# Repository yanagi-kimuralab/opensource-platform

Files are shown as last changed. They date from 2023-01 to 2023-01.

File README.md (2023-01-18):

# opensource-platform


# オープンソースプラットフォームとは
opensource-platformは、長岡技術科学大学木村研究室が開発・提供しているレスキュー対応ロボットのためのプラットフォームです。<br>
本プラットフォームはすべてのハードウェアがオープンソースハードウェアとして公開されています。

# 3Dモデルビューア
Autodesk Viewerを使用して、ブラウザ上で3Dモデルを閲覧・操作することができます。<br>
アクセスは[こちら](https://autode.sk/3wbROCn)から。

# 基本コンセプト
開発したプラットフォームは以下のコンセプトで開発されています。

・大学、高専生が製作可能であること<br>
・大学、高専等の設備で製造可能であること<br>
・様々な要求仕様に対応できること<br>
・災害対応ロボット競技会などの実証実験に使用できること<br>

# 基本仕様
オープンソースロボットプラットフォームの基本性能及びCADの書き方について以下に示します。



加工での注意点などは[wiki](https://github.com/yanagi-kimuralab/opensource-platform/wiki)に記載

# 使用ソフト環境
SOLIDWORKS 2018<br>
Vectric Cut2D<br>
Estlcam<br>

その他使用ソフトはこちら

ご不明なことがあればこちらに連絡ください。<br>
メール：stn.kimuralab@gmail.com

# ライセンス
opensource-platform is licensed under the Creative Commons Attribution-ShareAlike 4.0 International License.<br>
<br>

CADのライセンス問題があるため、SOLIDWORKSデータの提供については別途お問い合わせ願います。<br>

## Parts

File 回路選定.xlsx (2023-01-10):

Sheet: アークテクチャ記述
 | 使用アクチュエータ種類 | モータ 型番 |  |  | コネクタ |  | ケーブル |  | コネクタ | モータドライバ | コネクタ | ケーブル | コネクタ |  | サブCPU | ケーブル | メインPC
メインクローラL | モータ |  | 信号線 |  |  |  | 28AWG,10芯 |  | DIN 41651 | EPOS4 Compact 50/15 CAN | Molex CLIK-Mate, 1 列 , 4 極 (502578-0400) | ２８AWG ４芯 |  | CAN－BUSシールド | Arduino uno |  | NUC
 |  |  | 電源線 | モータ |  |  | 16AWG |  | Molex Mega-Fit, 4 極 (171692-0104) |  | Molex Mega-Fit, 2 極 (171692-0102) | 14AWG |  |  | ターミナル10P＊２ |  | ２４V バッテリー
メインクローラR | モータ |  |  |  | EHR-4 |  |  |  |  | EPOS4 Compact 50/15 CAN |  |  |  | CANシールド | Arduino uno
フリッパーFL | モータ | H54-200-S500-R | 信号線 |  |  |  | 28AWG,8芯 |  | molex SPOX™ | u2d2 | EHR-4 | ２８AWG ４芯 |  |  | デイジーチェーン
 |  |  | 電源線 |  |  |  | 16AWG |  | 39-01-2020
フリッパーFR | モータ | H54-200-S500-R |  |  |  |  |  |  |  | デイジーチェーン |  |  |  |  | デイジーチェーン
フリッパーRL | モータ | H54-200-S500-R |  |  |  |  |  |  |  | デイジーチェーン |  |  |  |  | デイジーチェーン
フリッパーRR | モータ | H54-200-S500-R |  |  |  |  |  |  |  | デイジーチェーン |  |  |  |  | デイジーチェーン
EPOS4 Compact 50/15 CAN |  | 最大出力電流Imax 30 A |  |  |  | 連続出力電流 Icount 15 A |  | 電源電圧Vcc (最大値) 50 V
https://www.maxongroup.co.jp/maxon/view/product/control/Positionierung/520886
 |  |  |  |  |  |  | 連続出力9.3A
ダイナミクセルモータ PH54-200-S500-R（H54-200-S500-R互換品
https://e-shop.robotis.co.jp/product.php?id=285

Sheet: 物品リスト
 | 箇所 | 区分 | 種類 | メーカ型番等 | サイト商品名 | 品番 | 注文コード | 必要個数 | 単価（税別） | 合計(税別 ) | 販売店 | リンク
 | メインクローラ | モータ |  |  | 組み合わせ ギアヘッド：プラネタリギアヘッド GP 42 C Ø42 mm, 3 - 15 Nm, セラミック･バージョン モータ：G32RE 40 Ø40 mm, グラファイトブラシ, 150 Watt センサ:エンコーダ MR, Type L, 500 カウント/回転, 3 チャンネル, ラインドライバ | 309293 |  | 2 | 117000 | 234000 | maxon | https://www.maxongroup.co.jp/maxon/view/content/cart
 | メインクローラ | MD |  | EPOS4 Compact 50/15 CAN | EPOS4 Compact 50/15 CAN, デジタル位置制御ユニット, 15 A, 10 - 50 VDC | 520886 |  | 4 | 80000 | 320000 | maxon | https://www.maxongroup.co.jp/maxon/view/product/control/Positionierung/520886
 | メインクローラ | 電源線 MD input（X1 | コネクタ ハウジング | Molex Mega-Fit, 2 極 (171692-0102) | Mega-Fit シリーズ 171692-0102、1個 | 171692-0102 | 29075105 | 40 | 58 | 2320 | モノタロウ | https://www.monotaro.com/p/2907/5105/ | 電線サイズ（AWG）:12～16
 | メインクローラ | 電源線 MD Output（X3b | コネクタ ハウジング | Molex Mega-Fit, 4 極 (171692-0104) | Mega-Fit シリーズ | 171692-0104 | 29075114 | 40 | 63 | 2520 | モノタロウ | https://www.monotaro.com/p/2907/5114/
 | メインクローラ | 電源線 MD | コネクタ コンタクト | Molex Mega-Fit, メスクリンプ端子 (172063) | Molex 端子 Mega-Fitシリーズ メス 圧着 | 172063-0311 | 58276576 | 2 | 7790 | 15580 | モノタロウ | https://www.monotaro.com/p/5827/6576/
 | メインクローラ | 電源線 MD→モータ | ケーブル | 14awg | FA用300V電源・低速移動屈曲配線ケーブルシールド有 | ロボトップ(DPC3-SB/2517)AWG14(2.0sq)2c | 34967055 | 5 | 1390 | 6950 | モノタロウ | https://www.monotaro.com/p/3496/7055/
 | メインクローラ | 電源線 ターミナル→MD | ケーブル | 1６awg | 16 awgシリコンワイヤ、20m / 66フィート柔軟で錫メッキされた銅線高耐熱10m黒と10m赤線は3Dプリンタ用、テストリード用、RCアプリ用 |  | B07H4HW3QY | 1 | ¥1999 | 1999 | アマゾン | https://www.amazon.co.jp/TUOFENG-16-awg%E3%82%B7%E3%83%AA%E3%82%B3%E3%83%B3%E3%83%AF%E3%82%A4%E3%83%A4%E3%80%8120m-66%E3%83%95%E3%82%A3%E3%83%BC%E3%83%88%E6%9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
 | メインクローラ | 信号線 MD CAN(X11 | コネクタ ハウジング | Molex CLIK-Mate, 1 列 , 4 極 (502578-0400) | Molex コネクタハウジング 4極 ピッチ：2mm 1列 502578-0400 | 896-7608 |  | 20 | ¥30.9 | 618 | RS | https://jp.rs-online.com/web/p/wire-housings-plugs/8967608/
 | メインクローラ | 信号線 MD CAN(X11 | コネクタ コンタクト | Molex CLIK-Mate クリンプ端子 (502579) | Molex 端子 CLIK-Mateシリーズ オス 圧着 | 720-6078 |  | 100 | ¥3.61 | 361 | RS | https://jp.rs-online.com/web/p/crimp-contacts/7206078/
 | メインクローラ | 信号線 MD エンコーダ(X5 | コネクタA | DIN 41651 メスコネクタ , ピッチ 2.54 mm, 10 極 , ストレイン･リリーフ付き) | リボンケーブルコネクタ RS Pro， メス， 10極， 2列 | 625-7369 | 41272273 | 20 | 379 | 7580 | モノタロウ | https://www.monotaro.com/p/4127/2273/
 | メインクローラ | 信号線 MD エンコーダ(X5 | コネクタB | DIN 41651 オスコネクタ , ピッチ 2.54 mm, 10 極 , ストレイン･リリーフ付き | RS PRO IDCコネクタ 10極, 2列 オス 2.54mmピッチ | 625-7252 |  | 4 | 344 | 1376 | RS | https://jp.rs-online.com/web/p/idc-connectors/6257252
 | メインクローラ | 信号線 MD エンコーダ(X5 | 圧接工具 |  | RS Pro 圧着工具 | 235-6428 | 41223763 | 1 | 3890 | 3890 | モノタロウ | https://www.monotaro.com/p/4122/3763/
 | メインクローラ | 信号線 10芯 シールド線 |  | 28AWG、10芯 | スリムロボットケーブル | KRT AWG28 X 10C 5m | 05233908 | 2 | 2990 | 5980 | モノタロウ | https://www.monotaro.com/p/0523/3908/
 | メインクローラ | 信号線 ４芯ケーブル |  | 26AWGぐらい12芯 | RKVリボンコード | RKV0.12mm/10CX12C 3m | 05234136 | 3 | 749 | 2247 | モノタロウ | https://www.monotaro.com/p/0523/4136/?t.q=%83%8A%83%7B%83%93%83P%81%5B%83u%83%8B%81%404%90c
税込み | メインクローラ | 信号線 | Arduino拡張 | SeeedStudio CAN-BUSシールド V2 | SeeedStudio CAN-BUSシールド V2 |  | SEEED-103030215 | 2 | 3421 | 6842 | SWITCHSCIENCE | https://www.switch-science.com/catalog/3435/
税込み | メインクローラ | 信号線 | Arduino |  | Arduino Uno R3 |  | ARDUINO-A000066 | 2 | 3300 | 6600 | SWITCHSCIENCE | https://www.switch-science.com/catalog/789/
税込み |  |  | usdケーブル | USB2.0ケーブル(A-Bタイプ) | USB2.0ケーブル(A-Bタイプ)50cm |  | SSCI-010337 | 2 | 165 | 330 | SWITCHSCIENCE | https://www.switch-science.com/catalog/1033/
 | フリッパー駆動 | モータ |  | PH54-200-S500-R | PH54-200-S500-R (H54P-200-S500-R) | 902-0079-001 | 8809052931605 | 4 | 280000 | 1120000 | ロボティズeショップ | https://e-shop.robotis.co.jp/product.php?id=285
 | フリッパー駆動 | 制御基板 |  | u2d2 | U2D2 | 902-0132-000 | 8809052930103 | 2 | 5000 | 10000 | ロボティズeショップ | https://e-shop.robotis.co.jp/product.php?id=190
追加 | フリッパー駆動 | 電源線 output | コネクタ ハウジング | Molex Mini-Fit Jr., 2 極 (39-01-2020 | Molex コネクタハウジング メス 2極 2列 4.2mm Mini-Fit Jrシリーズ | 39-01-3022 | 58272744 | 3 | 399 | 1197 | モノタロウ | https://www.monotaro.com/p/5827/2744/
追加 | フリッパー駆動 | 電源線 output | コネクタ コンタクト |  | Molex 圧着端子コンタクト メス MINI-FITシリーズ | 39-00-0038 | 41173415 | 1 | 529 | 529 | モノタロウ | https://www.monotaro.com/p/4117/3415/
税込み | フリッパー駆動 | 信号線 MD output | コネクタ ハウジング |  | SPOX™ハウジング4ピン10個入り |  | 4582221094120 | 5 | 759 | 3795 | アールティ | https://www.rt-shop.jp/index.php?main_page=product_info&cPath=1005_1178&products_id=780
税込み | フリッパー駆動 | 信号線 MD output | コネクタ 圧着端子 |  | SPOX™ターミナル50個入り |  | 4582221094106 | 5 | 550 | 2750 | アールティ | https://www.rt-shop.jp/index.php?main_page=product_info&products_id=783
 |  |  |  |  |  |  |  |  |  | 0
 | フリッパー駆動 | 信号線 u2d2 input | コネクタ ハウジング | EHR-4 | JST コネクタハウジング 4極 ピッチ：2.5mm 1列 EHR-4 | 311-6221 |  | 50 | 10.5 | 525 | RS | https://jp.rs-online.com/web/p/wire-housings-plugs/3116221/?matchtype=&pla-340042411389&gclsrc=aw.ds
 | フリッパー駆動 | 信号線 u2d2 input | コネクタ 圧着端子 |  | EHコネクタ コンタクト【100個入り】 | BEH-001T-P0.6 |  | 2 | 630 | 1260 | ミスミ | https://jp.misumi-ec.com/vona2/detail/110400201040/?searchFlow=results2products
 | フリッパー駆動 | 信号線 MD→モータ | ケーブル |  | スリムロボットケーブル | KRT AWG28 X 8C 3m | 05233874 | 2 | 1790 | 3580 | モノタロウ | https://www.monotaro.com/p/0523/3874/
 |  |  |  |  |  |  |  |  |  | 0
 | 全体 | 電源 ターミナル | 端子台 |  | ATK組端シリーズ【1～30個入り】 | ATK-15H-8P |  | 2 | 648 | 1296 | ミスミ | https://jp.misumi-ec.com/vona2/detail/222000169079/?HissuCode=ATK-15H-8P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
 | 全体 | 電源 ターミナル | ショートバー |  | ショートバー 被覆付き【1～10個入り】 | BB10-4 |  | 7 | 80 | 560 | ミスミ | https://jp.misumi-ec.com/vona2/detail/222000268305/?HissuCode=BB10-4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
 | 全体 | 電源 ターミナル | ショートバー |  | ショートバー 被覆付き【1～10個入り】 | BB10-2 |  | 9 | 60 | 540 | ミスミ | https://jp.misumi-ec.com/vona2/detail/222000268305/?HissuCode=BB10-2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
 | 全体 | 電源 ターミナル | コネクタ |  | 銅線用裸圧着端子（Y形）先開形【100個入り】 | 2Y-4 |  | 1 | 715 | 715 | ミスミ | https://jp.misumi-ec.com/vona2/detail/222000181286/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
 | 全体 | 電源→NUC | 可変コンバータ |  | dcdc 降圧モジュール DROK DC 24V / 12V / 5V 降圧降圧電源 モジュール 8-35V〜1.5-24V 可変コンバータ | B07B3S5H3M |  | 3 | 1758 | 5274 | アマゾン | https://www.amazon.co.jp/dcdc-%E9%99%8D%E5%9C%A7%E3%83%A2%E3%82%B8%E3%83%A5%E3%83%BC%E3%83%AB-DROK-DC-24V-12V-5V-%E9%99%8D%E5%9C%A7%E9%99%8D%E5%9C%A7%E9%9B%BB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
 |  |  | 熱伝導性両面テープ |  | 熱伝導性両面テープ 8926-02 | 8926-025-100X100-1P |  | 1 | 1282 | 1282 | ミスミ | https://jp.misumi-ec.com/vona2/detail/223013678394/?HissuCode=8926-025-100X100-1P&list=PageDetail
 |  | 非常停止 |  |  | スイッチボックス SBOX IDEC IP65相当防水タイプ スイッチ1点付き | NGC-132 |  | 2 | 3989 | 7978 | ミスミ | https://jp.misumi-ec.com/vona2/detail/222303534903/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
 |  | NUC | NUC | ‎RNUC11PAHi70000 | インテル NUC 第 11 世代 Core プロセッサー・ファミリー搭載 NUC キット「NUC11PAHi7」ACコードなし |  | B093BN4TX6 | 1 | 70404 | 70404 | アマゾン | https://www.amazon.co.jp/%E3%82%A4%E3%83%B3%E3%83%86%E3%83%AB-NUC-Core-%E3%83%97%E3%83%AD%E3%82%BB%E3%83%83%E3%82%B5%E3%83%BC%E3%83%BB%E3%83%95%E3%82%A1%E3%83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
 |  |  | SSD |  | SAMSUNG 980 PRO MZ-V8P500B/IT |  | 769041 | 1 | 14528 | 14528 | パソコン工房 | https://www.pc-koubou.jp/products/detail.php?product_id=769041
 |  |  | メモリ |  | CFD D4N2666CM-16G |  | 614685 | 1 | 8668 | 8668 | パソコン工房 | https://www.pc-koubou.jp/products/detail.php?product_id=614685
 |  | グロメット |  |  | グロメットNG 型 (https://www.monotaro.com/g/01032105/) | PG-4 NG-79-F | 01671495 | 3 | 99 | 297 | モノタロウ | https://www.monotaro.com/p/0167/1495/?t.q=%83O%83%8D%83%81%83b%83g
 |  |  | コネクタ |  | JUTOSU XT60コネクター コネクタープラグ オス&メス XT60 RC バレット リポバッテリー用 10ペア |  | B08J41DVZG | 3 | 699 | 2097 | アマゾン | https://www.amazon.co.jp/JTMIX-XT60%E3%82%B3%E3%83%8D%E3%82%AF%E3%82%BF%E3%83%BC-%E3%82%B3%E3%83%8D%E3%82%AF%E3%82%BF%E3%83%BC%E3%83%97%E3%83%A9%E3%82%B0-XT60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
 |  |  | バッテリー |  | SIGP 6S 22.2Vリポバッテリー2200mAh 40Cソフトパックfor RCヘリコプター飛行機FPVドローンクワッドコプターレーシングホビー |  | B08ZCV1Q2T | 2 | 4639 | 9278 | アマゾン | https://www.amazon.co.jp/SIGP-6S-22-2V%E3%83%AA%E3%83%9D%E3%83%90%E3%83%83%E3%83%86%E3%83%AA%E3%83%BC2200mAh-40C%E3%82%BD%E3%83%95%E3%83%88%E3%83%91%E3%83%83%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
 | ケーブルAWG規格表 |  | https://www.batteryspace.jp/html/page28.html |  |  |  |  |  |  | 1331746
 | https://www.molex.com/molex/products/part-detail/crimp_housings/1716920102
 | ダイナミクセルモータ 詳細説明サイト
 | https://emanual.robotis.com/docs/en/dxl/p/ph54-200-s500-r/

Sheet: モノタロウ
サイト商品名 | 品番 | 注文コード | 必要個数 | 単価（税別） | 合計(税別 ) | リンク
Mega-Fit シリーズ 171692-0102、1個 | 171692-0102 | 29075105 | 40 | 58 | 2320 | https://www.monotaro.com/p/2907/5105/
Mega-Fit シリーズ 極数 4、定格電流 23A、(インシュレータ)黒、171692-0104、1個 | 171692-0104 | 29075114 | 40 | 63 | 2520 | https://www.monotaro.com/p/2907/5114/
Molex 端子 Mega-Fitシリーズ メス 圧着 172063-0311、1袋(100個) | 172063-0311 | 58276576 | 2 | 7790 | 15580 | https://www.monotaro.com/p/5827/6576/
FA用300V電源・低速移動屈曲配線ケーブルシールド有 2C、電線太さ 2mm2、全長 2m、1巻 | ロボトップ(DPC3-SB/2517)AWG14(2.0sq)2c | 34967055 | 5 | 1390 | 6950 | https://www.monotaro.com/p/3496/7055/
リボンケーブルコネクタ RS Pro， メス， 10極， 2列 625-7369、1個 | 625-7369 | 41272273 | 20 | 379 | 7580 | https://www.monotaro.com/p/4127/2273/
RS Pro 圧着工具 235-6428、1個 | 235-6428 | 41223763 | 1 | 3890 | 3890 | https://www.monotaro.com/p/4122/3763/
スリムロボットケーブル 10C、全長 5m、AWG 28、導体公称断面積 0.1mm2、1個 | KRT AWG28 X 10C 5m | 05233908 | 2 | 2990 | 5980 | https://www.monotaro.com/p/0523/3908/
RKVリボンコード 12C、導体公称断面積 0.1mm2、全長 3m、1個 | RKV0.12mm/10CX12C 3m | 05234136 | 3 | 749 | 2247 | https://www.monotaro.com/p/0523/4136/?t.q=%83%8A%83%7B%83%93%83P%81%5B%83u%83%8B%81%404%90c
スリムロボットケーブル 8C、全長 3m、AWG 28、導体公称断面積 0.1mm2、1個 | KRT AWG28 X 8C 3m | 05233874 | 2 | 1790 | 3580 | https://www.monotaro.com/p/0523/3874/
グロメットNG 型 色 黒色 1袋(10個) | PG-4 NG-79-F | 01671495 | 3 | 99 | 297 | https://www.monotaro.com/p/0167/1495/?t.q=%83O%83%8D%83%81%83b%83g
 |  |  |  |  | 50944

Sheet: ミスミ
サイト商品名 | 型番 | 必要個数 | 単価（税別） | 合計(税別 ) | リンク
EHコネクタ コンタクト【100個入り】 | BEH-001T-P0.6 | 2 | 630 | 1260 | https://jp.misumi-ec.com/vona2/detail/110400201040/?searchFlow=results2products
ATK組端シリーズ【1～30個入り】 | ATK-15H-8P | 2 | 648 | 1296 | https://jp.misumi-ec.com/vona2/detail/222000169079/?HissuCode=ATK-15H-8P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
ショートバー 被覆付き【1～10個入り】 | BB10-4 | 10 | 80 | 800 | https://jp.misumi-ec.com/vona2/detail/222000268305/?HissuCode=BB10-4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
ショートバー 被覆付き【1～10個入り】 | BB10-2 | 10 | 60 | 600 | https://jp.misumi-ec.com/vona2/detail/222000268305/?HissuCode=BB10-2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
銅線用裸圧着端子（Y形）先開形【100個入り】 | 2Y-4 | 1 | 715 | 715 | https://jp.misumi-ec.com/vona2/detail/222000181286/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
熱伝導性両面テープ 8926-02 | 8926-025-100X100-1P | 1 | 1282 | 1282 | https://jp.misumi-ec.com/vona2/detail/223013678394/?HissuCode=8926-025-100X100-1P&list=PageDetail
スイッチボックス SBOX IDEC IP65相当防水タイプ スイッチ1点付き | NGC-132 | 2 | 3989 | 7978 | https://jp.misumi-ec.com/vona2/detail/222303534903/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
ロッド | RDOS8-49-WMC4 | 20 | 799 | 15980 | https://jp.misumi-ec.com/vona2/detail/110300229450/?PNSearch=RDOS8-49-WMC4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
ロッド | RDOS8-95-WMC4 | 12 | 820 | 9840 | https://jp.misumi-ec.com/vona2/detail/110300229450/?HissuCode=RDOS8-95-WMC4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
ロッド | RDOS6-99-WMC3 | 10 | 820 | 8200 | https://jp.misumi-ec.com/vona2/detail/110300229450/?HissuCode=RDOS6-99-WMC3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
Oリング NOK Sシリーズ（固定用） | S36-1A | 20 | 65 | 1300 | https://jp.misumi-ec.com/vona2/detail/221000051416/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
 |  |  |  | 49251

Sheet: RS
サイト商品名 | RS品番 | メーカ型番 | 必要個数 | 単価（税別） | 合計(税別 ) | 販売店 | リンク
Molex コネクタハウジング 4極 ピッチ：2mm 1列 502578-0400 | 896-7608 | 502578-0400 | 20 | ¥30.9 | 618 | RS | https://jp.rs-online.com/web/p/wire-housings-plugs/8967608/
Molex 端子 CLIK-Mateシリーズ オス 圧着 | 720-6078 | 502579-0000 | 100 | ¥3.61 | 361 | RS | https://jp.rs-online.com/web/p/crimp-contacts/7206078/
RS PRO IDCコネクタ 10極, 2列 オス 2.54mmピッチ | 625-7252 |  | 6 | ¥344.0 | 2064 | RS | https://jp.rs-online.com/web/p/idc-connectors/6257252
JST コネクタハウジング 4極 ピッチ：2.5mm 1列 EHR-4 | 311-6221 | EHR-4 | 50 | ¥7.8 | 390 | RS | https://jp.rs-online.com/web/p/wire-housings-plugs/3116221/
 |  |  |  |  | 3433

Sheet: Amazon
サイト商品名 | ASIN | 必要個数 | 単価（税込み） | 合計(税込み ) | リンク
16 awgシリコンワイヤ、20m / 66フィート柔軟で錫メッキされた銅線高耐熱10m黒と10m赤線は3Dプリンタ用、テストリード用、RCアプリ用 | B07H4HW3QY | 1 | ¥1999 | 1999 | https://www.amazon.co.jp/dp/B07H4HW3QY?s=industrial&viewID=
dcdc 降圧モジュール DROK DC 24V / 12V / 5V 降圧降圧電源 モジュール 8-35V〜1.5-24V 可変コンバータ | B07B3S5H3M | 3 | 1758 | 5274 | https://www.amazon.co.jp/dcdc-%E9%99%8D%E5%9C%A7%E3%83%A2%E3%82%B8%E3%83%A5%E3%83%BC%E3%83%AB-DROK-DC-24V-12V-5V-%E9%99%8D%E5%9C%A7%E9%99%8D%E5%9C%A7%E9%9B%BB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
インテル NUC 第 11 世代 Core プロセッサー・ファミリー搭載 NUC キット「NUC11PAHi7」ACコードなし | B093BN4TX6 | 1 | 70404 | 70404 | https://www.amazon.co.jp/%E3%82%A4%E3%83%B3%E3%83%86%E3%83%AB-NUC-Core-%E3%83%97%E3%83%AD%E3%82%BB%E3%83%83%E3%82%B5%E3%83%BC%E3%83%BB%E3%83%95%E3%82%A1%E3%83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
JUTOSU XT60コネクター コネクタープラグ オス&メス XT60 RC バレット リポバッテリー用 10ペア | B08J41DVZG | 3 | 699 | 2097 | https://www.amazon.co.jp/JTMIX-XT60%E3%82%B3%E3%83%8D%E3%82%AF%E3%82%BF%E3%83%BC-%E3%82%B3%E3%83%8D%E3%82%AF%E3%82%BF%E3%83%BC%E3%83%97%E3%83%A9%E3%82%B0-XT60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
SIGP 6S 22.2Vリポバッテリー2200mAh 40Cソフトパックfor RCヘリコプター飛行機FPVドローンクワッドコプターレーシングホビー | B08ZCV1Q2T | 2 | 4639 | 9278 | https://www.amazon.co.jp/SIGP-6S-22-2V%E3%83%AA%E3%83%9D%E3%83%90%E3%83%83%E3%83%86%E3%83%AA%E3%83%BC2200mAh-40C%E3%82%BD%E3%83%95%E3%83%88%E3%83%91%E3%83%83%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
 |  |  |  | 89052

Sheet: ロボティズeショップ
サイト商品名 | 品番 | JANコード | 必要個数 | 単価（税込み） | 合計(税込み ) | リンク
PH54-200-S500-R (H54P-200-S500-R) | 902-0079-001 | 8809052931605 | 4 | 308000 | 1232000 | https://e-shop.robotis.co.jp/product.php?id=285
U2D2 | 902-0132-000 | 8809052930103 | 2 | 5500 | 11000 | https://e-shop.robotis.co.jp/product.php?id=190
 |  |  |  |  | 1243000

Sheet: maxon
サイト商品名 | 製品番号 | 必要個数 | 単価（税別） | 合計(税別 ) | リンク
組み合わせ ギアヘッド：プラネタリギアヘッド GP 42 C Ø42 mm, 3 - 15 Nm, セラミック･バージョン モータ：G32RE 40 Ø40 mm, グラファイトブラシ, 150 Watt センサ:エンコーダ MR, Type L, 500 カウント/回転, 3 チャンネル, ラインドライバ | 309293 | 2 | 117000 | 234000 | https://www.maxongroup.co.jp/maxon/view/content/cart
EPOS4 Compact 50/15 CAN, デジタル位置制御ユニット, 15 A, 10 - 50 VDC | 520886 | 2 | 80000 | 160000 | https://www.maxongroup.co.jp/maxon/view/product/control/Positionierung/520886
 |  |  |  | 394000

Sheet: アールティ
サイト商品名 | JANコード | 必要個数 | 単価（税込み） | 合計(税込み ) | リンク
SPOX™ハウジング4ピン10個入り | 4582221094120 | 5 | 759 | 3795 | https://www.rt-shop.jp/index.php?main_page=product_info&cPath=1005_1178&products_id=780
SPOX™ターミナル50個入り | 4582221094106 | 5 | 550 | 2750 | https://www.rt-shop.jp/index.php?main_page=product_info&products_id=783
 |  |  |  | 6545

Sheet: パソコン工房
サイト商品名 | 商品ID | 必要個数 | 単価（税別） | 合計(税別 ) | リンク
SAMSUNG 980 PRO MZ-V8P500B/IT | 769041 | 1 | 14528 | 14528 | https://www.pc-koubou.jp/products/detail.php?product_id=769041
CFD D4N2666CM-16G | 614685 | 1 | 7880 | 7880 | https://www.pc-koubou.jp/products/detail.php?product_id=614685
 |  |  |  | 22408

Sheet: SWITCHSCIENCE
サイト商品名 | コード番号 | 必要個数 | 単価（税込み） | 合計(税込み ) | リンク
SeeedStudio CAN-BUSシールド V2 | SEEED-103030215 | 2 | 3421 | 6842 | https://www.switch-science.com/catalog/3435/
Arduino Uno R3 | ARDUINO-A000066 | 2 | 3300 | 6600 | https://www.switch-science.com/catalog/789/
USB2.0ケーブル(A-Bタイプ)50cm | SSCI-010337 | 2 | 165 | 330 | https://www.switch-science.com/catalog/1033/

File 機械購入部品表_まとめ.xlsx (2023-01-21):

パーツ名 | 品番 | 購入場所 | 個数 | 単価(税別) | 合計金額 | URL
アルミ平板 2mm | HA2230 | モノタロウ | 3 | 999 | 2997 | HA2230 アルミ平板 光 アルミ 厚さ2mm幅200mm長さ300mm 1枚 - 【通販モノタロウ】 (monotaro.com) (https://www.monotaro.com/p/3576/7103/)
アルミニウム板(A2017) 3mm | MPAL2C-200×400×t3 | モノタロウ | 3 | 4790 | 14370 | MPAL2C-200×400×t3 アルミニウム板(A2017) アズワン 寸法200×400mm板厚3mm 1個 - 【通販モノタロウ】 (monotaro.com) (https://www.monotaro.com/p/2015/3289/)
アルミニウム板(A2017) 5mm | MPAL2C-200×400×t5 | モノタロウ | 3 | 7750 | 23250 | MPAL2C-200×400×t5 アルミニウム板(A2017) アズワン 寸法200×400mm板厚5mm 1個 - 【通販モノタロウ】 (monotaro.com) (https://www.monotaro.com/p/2015/4375/)
アルミニウム板(A2017) 6mm | MPAL2C-200×400×t6 | モノタロウ | 14 | 8810 | 123340 | MPAL2C-200×400×t6 アルミニウム板(A2017) アズワン 寸法200×400mm板厚6mm 1個 - 【通販モノタロウ】 (monotaro.com) (https://www.monotaro.com/p/2015/4926/)
アルミニウム板(A2017) 8mm | MPAL2C-200×400×t8 | モノタロウ | 4 | 11900 | 47600 | MPAL2C-200×400×t8 アルミニウム板(A2017) アズワン 寸法200×400mm板厚8mm 1個 - 【通販モノタロウ】 (monotaro.com) (https://www.monotaro.com/p/2015/5477/)
アルミニウム板(A2017) 10mm | MPAL2C-200×400×t10 | モノタロウ | 3 | 14400 | 43200 | MPAL2C-200×400×t10 アルミニウム板(A2017) アズワン 寸法200×400mm板厚10mm 1個 - 【通販モノタロウ】 (monotaro.com) (https://www.monotaro.com/p/2015/6028/)
PLAフィラメント | 17060724 | モノタロウ | 2 | 5000 | 10000 | PLAフィラメント MUTOH フィラメント 【通販モノタロウ】 (monotaro.com) (https://www.monotaro.com/g/01253342/)
シンクロベルト H形（ゴム） | 330H075 | ミスミ | 8 | 3010 | 24080 | 330H075 | シンクロベルト H形（ゴム） | バンドー化学 | MISUMI(ミスミ) (misumi-ec.com) (https://jp.misumi-ec.com/vona2/detail/221004989892/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)
単列深溝玉軸受（開放形／シール形／シールド形） | 6802DDU(ZZ) | ミスミ | 6 | 534 | 3204 | 6802DDU | 単列深溝玉軸受（開放形／シール形／シールド形） | ＮＳＫ | MISUMI(ミスミ) (misumi-ec.com) (https://jp.misumi-ec.com/vona2/detail/221000058301/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)
単列深溝玉軸受（開放形／シール形／シールド形） | 6806DDU(ZZ) | ミスミ | 6 | 763 | 4578 | 6806DDU | 単列深溝玉軸受（開放形／シール形／シールド形） | ＮＳＫ | MISUMI(ミスミ) (misumi-ec.com) (https://jp.misumi-ec.com/vona2/detail/221000058301/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)
円形支柱－両端めねじ | SETF6-20-M3-N3 | ミスミ | 8 | 492 | 3936 | https://jp.misumi-ec.com/vona2/detail/110300208270/?HissuCode=SETF6-20-M3-N3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
深溝玉軸受 両シールド形 | B6800ZZ | ミスミ | 8 | 380 | 3040 | B6800ZZ | 深溝玉軸受 両シールド形 | ミスミ | MISUMI(ミスミ) (misumi-ec.com) (https://jp.misumi-ec.com/vona2/detail/110300107740/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)
CNRゴムシート | CPL-100(60) | モノタロウ | 2 | 2490 | 4980 | CPL-100(60) CNRゴムシート 十川ゴム 黒色 厚さ10mm幅300mm長さ300mm 1枚 - 【通販モノタロウ】 (monotaro.com) (https://www.monotaro.com/p/0705/7425/)
小径玉軸受 フランジ付両シールド形 | FL6805ZZ | ミスミ | 8 | 3150 | 25200 | FL6805ZZ | 小径玉軸受 フランジ付両シールド形 | ミスミ | MISUMI(ミスミ) (misumi-ec.com) (https://jp.misumi-ec.com/vona2/detail/110300107650/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)
シェル形針状ころ軸受 外輪付き | HK1512 | ミスミ | 4 | 220 | 880 | HK1512 | シェル形針状ころ軸受 外輪付き | ＮＴＮ | MISUMI(ミスミ) (misumi-ec.com) (https://jp.misumi-ec.com/vona2/detail/221000068571/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)
無給油ブッシュ ポリアセタール樹脂タイプ ツバ付 | JZF6-10 | ミスミ | 8 | 330 | 2640 | JZF6-10 | 無給油ブッシュ ポリアセタール樹脂タイプ ツバ付 | ミスミ | MISUMI(ミスミ) (misumi-ec.com) (https://jp.misumi-ec.com/vona2/detail/110302640340/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)
平行キー | KEGS5-LC30 | ミスミ | 2 | 550 | 1100 | 平行キー | ミスミ | MISUMI(ミスミ) (misumi-ec.com) (https://jp.misumi-ec.com/vona2/detail/110302681730/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)
平行キー | KESF5-23 | ミスミ | 2 | 350 | 700 | 平行キー | ミスミ | MISUMI(ミスミ) (misumi-ec.com) (https://jp.misumi-ec.com/vona2/detail/110302681730/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)
スリムロボットケーブル | KRT AWG28 X 8C 3m | モノタロウ | 2 | 1790 | 3580 | KRT AWG28 X 8C 3m スリムロボットケーブル 1個 協和ハーモネット 【通販モノタロウ】 (monotaro.com) (https://www.monotaro.com/p/0523/3874/)
スリムロボットケーブル | KRT AWG28 X 10C 5m | モノタロウ | 2 | 2990 | 5980 | KRT AWG28 X 10C 5m スリムロボットケーブル 1個 協和ハーモネット 【通販モノタロウ】 (monotaro.com) (https://www.monotaro.com/p/0523/3908/)
駆動軸 ツバ付タイプ | KZES15-106-T10-P15-LA42-NA5-KB18-HB23-AA180-WA0-GA16 | ミスミ | 2 | 5410 | 10820 | 駆動軸 ツバ付タイプ | ミスミ | MISUMI(ミスミ) (misumi-ec.com) (https://jp.misumi-ec.com/vona2/detail/110300099070/?searchFlow=results2products)
メガトルクG タイミングベルト MTS5M形(高硬度合成ゴム) | 100MTS5M390G | モノタロウ | 4 | 1490 | 5960 | 100MTS5M390 メガトルクG タイミングベルト MTS5M形(高硬度合成ゴム) 三ツ星ベルト 標準タイプ ベルト幅10mmベルトピッチ周長390mm - 【通販モノタロウ】 (monotaro.com) (https://www.monotaro.com/p/4785/9987/)
Ｏリング Ｇシリーズ | NGS25 | ミスミ | 7 | 102 | 714 | Ｏリング Ｇシリーズ | ミスミ | MISUMI(ミスミ) (misumi-ec.com) (https://jp.misumi-ec.com/vona2/detail/110302229710/?PNSearch=NGS25&KWSearch=NGS25&searchFlow=results2products)
グロメットNG 型 | PG-4 NG-79-F | モノタロウ | 12 | 109 | 1308 | PG-4 NG-79-F グロメットNG 型 1袋(10個) ジョー・プリンス竹下 【通販モノタロウ】 (monotaro.com) (https://www.monotaro.com/p/0167/1495/)
膜付グロメット | PG-6 SG-12A | モノタロウ | 1 | 319 | 319 | PG-6 SG-12A 膜付グロメット ジョー・プリンス竹下 黒色 - 【通販モノタロウ】 (monotaro.com) (https://www.monotaro.com/p/0167/1933/?t.q=PG-6%20SG-12A)
樹脂パイプ -内外形仕上タイプ- | PIJJ14-8-58 | ミスミ | 4 |  | 0 | 樹脂パイプ -内外形仕上タイプ- | ミスミ | MISUMI(ミスミ) (misumi-ec.com) (https://jp.misumi-ec.com/vona2/detail/110300231550/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)
樹脂パイプ -内外形仕上タイプ- | PIJJ14-8-87 | ミスミ | 8 |  | 0 | 樹脂パイプ -内外形仕上タイプ- | ミスミ | MISUMI(ミスミ) (misumi-ec.com) (https://jp.misumi-ec.com/vona2/detail/110300231550/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)
樹脂パイプ -内外形仕上タイプ- | PIJJ20-8-90 | ミスミ | 4 |  | 0 | 樹脂パイプ -内外形仕上タイプ- | ミスミ | MISUMI(ミスミ) (misumi-ec.com) (https://jp.misumi-ec.com/vona2/detail/110300231550/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)
ロッド（ステンレス・アルミ黄銅・純チタン2種) | RDOS6-99-WMC3 | ミスミ | 4 | 820 | 3280 | ロッド（ステンレス・アルミ黄銅・純チタン2種) | ミスミ | MISUMI(ミスミ) (misumi-ec.com) (https://jp.misumi-ec.com/vona2/detail/110300229450/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)
ロッド（ステンレス・アルミ黄銅・純チタン2種) | RDOS8-49-WMC4 | ミスミ | 16 | 820 | 13120 | ロッド（ステンレス・アルミ黄銅・純チタン2種) | ミスミ | MISUMI(ミスミ) (misumi-ec.com) (https://jp.misumi-ec.com/vona2/detail/110300229450/?HissuCode=RDOS8-49-WMC4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)
ロッド（ステンレス・アルミ黄銅・純チタン2種) | RDOS8-65-WMC4 | ミスミ | 4 | 820 | 3280 | ロッド（ステンレス・アルミ黄銅・純チタン2種) | ミスミ | MISUMI(ミスミ) (misumi-ec.com) (https://jp.misumi-ec.com/vona2/detail/110300229450/?PNSearch=RDOS8-65-WMC4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)
ロッド（ステンレス・アルミ黄銅・純チタン2種) | RDOS8-95-WMC4 | ミスミ | 8 | 820 | 6560 | ロッド（ステンレス・アルミ黄銅・純チタン2種) | ミスミ | MISUMI(ミスミ) (misumi-ec.com) (https://jp.misumi-ec.com/vona2/detail/110300229450/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)
TW形 スラストワッシャ | R-TW1530 | モノタロウ | 4 | 72 | 288 | R-TW1530 TW形 スラストワッシャ 1個 エヌティーエヌ(NTN) 【通販モノタロウ】 (monotaro.com) (https://www.monotaro.com/p/0044/4236/?t.q=%83X%83%89%83X%83g%83%8F%83b%83V%83%83%81%5B)
CR布入りゴムシート | 22256456 | モノタロウ | 1 | 18900 | 18900 | 1000×1000×3mm CR布入りゴムシート ノーブランド 3mm厚 幅1000mm長さ1000mm - 【通販モノタロウ】 (monotaro.com) (https://www.monotaro.com/g/01407113/?t.q=22256456)
Oリング NOK Sシリーズ（固定用） | S36-1A | ミスミ | 6 | 73 | 438 | S36-1A | Oリング NOK Sシリーズ（固定用） | ＮＯＫ | MISUMI(ミスミ) (misumi-ec.com) (https://jp.misumi-ec.com/vona2/detail/221000051416/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)
回転軸 両端めねじタイプ | SSFHRW15-75-MD5-ND5-KC45-A30-SFC0-SG16-AG180 | ミスミ | 2 | 2120 | 4240 | 回転軸 両端めねじタイプ | ミスミ | MISUMI(ミスミ) (misumi-ec.com) (https://jp.misumi-ec.com/vona2/detail/110300089020/?searchFlow=results2products)
ワンタッチグロメット 耐候タイプ T-1458型 | T-145825 | モノタロウ | 1 | 5990 | 5990 | T-1458253-P50 ワンタッチグロメット 耐候タイプ T-1458型 1セット(50個) スガツネ(LAMP) 【通販モノタロウ】 (monotaro.com) (https://www.monotaro.com/p/2570/6039/)
ポリアセタール板（POM）T=5mm 仕上げ : フライス | POM T=5×200×300(白) | オリジナルマインド | 1 | 1820 | 1820 | ポリアセタール板（POM）T=5mm 仕上げ : フライス | ORIGINALMIND オリジナルマインド (https://www.originalmind.co.jp/goods/03542)
ステンレス六角穴付きボルト【1～1,000個入り】 | KKT-HCSNNSZC3-10 | ミスミ | 244 | 9 | 2196 | ステンレス六角穴付きボルト | 極東製作所 | MISUMI(ミスミ) (misumi-ec.com) (https://jp.misumi-ec.com/vona2/detail/221000530250/?searchFlow=results2products)
十字穴付（+）皿小ねじ【1～15,000個入り】 | CSPCSZ-316L-M3-10 | ミスミ | 412 | 15 | 6180 | 十字穴付（+）皿小ねじ | ＳＵＮＣＯ | MISUMI(ミスミ) (misumi-ec.com) (https://jp.misumi-ec.com/vona2/detail/221000547315/)
十字穴付（+）皿小ねじ【1～15,000個入り】 | CSPCSZ-316L-M3-30 | ミスミ | 64 | 36 | 2304 | 十字穴付（+）皿小ねじ | ＳＵＮＣＯ | MISUMI(ミスミ) (misumi-ec.com) (https://jp.misumi-ec.com/vona2/detail/221000547315/)
六角穴付ボルト(ステンレス) 全ねじ | M3×12 | モノタロウ | 2 | 729 | 1458 | M3×12 六角穴付ボルト(ステンレス) 全ねじ 大阪魂 呼びM3長さ12mm 1パック(54個) - 【通販モノタロウ】 (monotaro.com)
六角穴付ボルト(ステンレス) 全ねじ | M3×16 | モノタロウ | 1 | 729 | 729 | M3×16 六角穴付ボルト(ステンレス) 全ねじ 大阪魂 呼びM3長さ16mm 1パック(50個) - 【通販モノタロウ】 (monotaro.com) (https://www.monotaro.com/p/2901/7748/)
六角穴付ボルト(ステンレス) 全ねじ | M3×25 | モノタロウ | 1 | 599 | 599 | M3×25 六角穴付ボルト(ステンレス) 全ねじ 大阪魂 呼びM3長さ25mm 1パック(30個) - 【通販モノタロウ】 (monotaro.com) (https://www.monotaro.com/p/6891/0643/)
六角穴付ボルト(ステンレス) 全ねじ | M3×30 | モノタロウ | 2 | 599 | 1198 | M3×30 六角穴付ボルト(ステンレス) 全ねじ 大阪魂 呼びM3長さ30mm 1パック(25個) - 【通販モノタロウ】 (monotaro.com) (https://www.monotaro.com/p/6891/0652/)
六角穴付ボルト(ステンレス) 全ねじ | M4×12 | モノタロウ | 1 | 729 | 729 | M4×12 六角穴付ボルト(ステンレス) 全ねじ 大阪魂 呼びM4長さ12mm 1パック(49個) - 【通販モノタロウ】 (monotaro.com) (https://www.monotaro.com/p/2901/7793/)
六角穴付ボルト(ステンレス) 全ねじ | M5×45 | モノタロウ | 2 | 729 | 1458 | M5×45 六角穴付ボルト(ステンレス) 全ねじ 大阪魂 呼びM5長さ45mm 1パック(24個) - 【通販モノタロウ】 (monotaro.com) (https://www.monotaro.com/p/2901/8344/)
六角穴付皿ボルト －ステンレス・小箱－【20～2,000個入り】 | PACK-SFB3-10 | ミスミ | 1 | 1550 | 1550 | M3-10 六角穴付皿ボルト －ステンレス・小箱| MISUMI(ミスミ) (misumi-ec.com) (https://jp.misumi-ec.com/vona2/detail/110301997650/?PNSearch=PACK-SFB3-10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)
六角穴付皿ボルト －ステンレス・小箱－【20～2,000個入り】 | PACK-SFB3-12 | ミスミ | 1 | 1650 | 1650 | M3-12 六角穴付皿ボルト －ステンレス・小箱| MISUMI(ミスミ) (misumi-ec.com) (https://jp.misumi-ec.com/vona2/detail/110301997650/?PNSearch=PACK-SFB3-12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)
六角穴付止めねじ 平先【1～1,000個入り】 | SSHHA-SUS-M3-30 | ミスミ | 8 | 110 | 880 | M3-30 六角穴付止めねじ 平先 | ＳＵＮＣＯ | MISUMI(ミスミ) (misumi-ec.com) (https://jp.misumi-ec.com/vona2/detail/221000551567/?HissuCode=SSHHA-SUS-M3-30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)
六角穴付き皿ボルト（皿キャップスクリュー）【1～2,000個入り】 | CSHCS-316L-M4-10 | ミスミ | 8 | 43 | 344 | M4-10 六角穴付き皿ボルト | ＳＵＮＣＯ | MISUMI(ミスミ) (misumi-ec.com) (https://jp.misumi-ec.com/vona2/detail/221000551376/?PNSearch=CSHCS-316L-M4-10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)
六角穴付き皿ボルト（皿キャップスクリュー）【1～2,000個入り】 | CSHCS-SUS-M4-25 | ミスミ | 24 | 58 | 1392 | M4-10 六角穴付き皿ボルト | ＳＵＮＣＯ | MISUMI(ミスミ) (misumi-ec.com) (https://jp.misumi-ec.com/vona2/detail/221000551376/?PNSearch=CSHCS-SUS-M4-25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)
 |  |  |  | 合計 | 446967

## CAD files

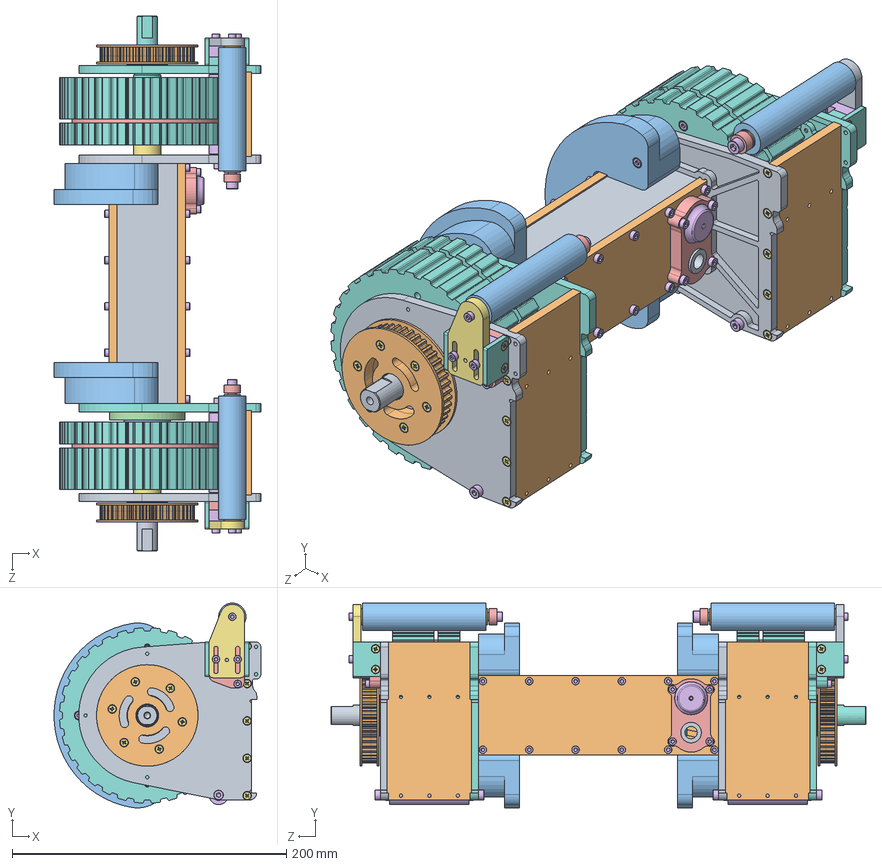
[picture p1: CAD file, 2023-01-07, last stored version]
OpenSource-Platform for publication/Driving crawler_Unit.SLDASM
150.7 x 149.4 x 390.0 mm
Driving crawler_Motor box_Plate_Side A B x 2
Driving crawler_Motor box_Plate_Side L R x 2
Driving crawler_Sliding Idler x 2
maxon RE40+GP42C+HEDL5540_374679
Driving flipper_Grommet mounting plate
T-145825
S36-1A
Driving crawler_Holding timing pulley plate_Mirror x 2
Driving crawler_Holding timing pulley plate x 2
Driving crawler_Holding timing pulley plate_Base x 2
Driving crawler_Timing pulley_Center attachment_Near motor x 3
Driving crawler_Bearing holder
Driving crawler_Timing pulley_Partition plate x 2
Driving crawler_Timing pulley_Center attachment x 5
Driving crawler_Timing pulley shaft_Spacer x 3
Driving crawler_Timing pulley x 4
SSFHRW15-75-MD5-ND5-KC45-A30-SFC0-SG16-AG180
KEGS5-LC30
6806DDU(ZZ)
6802DDU(ZZ) x 3
RDOS8-65-WMC4 x 2
PIJJ14-8-58 x 2
NGS25
KZES15-106-T10-P15-LA42-NA5-KB18-HB23-AA180-WA0-GA16
KESF5-23
Driving crawler_Driven pulley x 4
HK1512 x 2
R-TW1530 x 2
Driving crawler_Tensioner_Positioning plate _Inside
Driving crawler_Tensioner_Positioning plate _Outside x 2
Driving crawler_Tensioner_Holding cantilever
Driving crawler_Tensioner_Positioning plate _Inside_Mirror
Driving crawler_Tensioner_Holding cantilever_Mirror
JZF6-10 x 4
PIJJ20-8-90 x 2
RDOS6-99-WMC3 x 2
Driving crawler_Tensioner_Shaft attachment x 2
hexagon socket head cap screw_jis x 66
cross recessed countersunk head screw_jis x 68
Driving crawler_Tensioner_Positioning plate _Support x 4
PG-4 NG-79-F

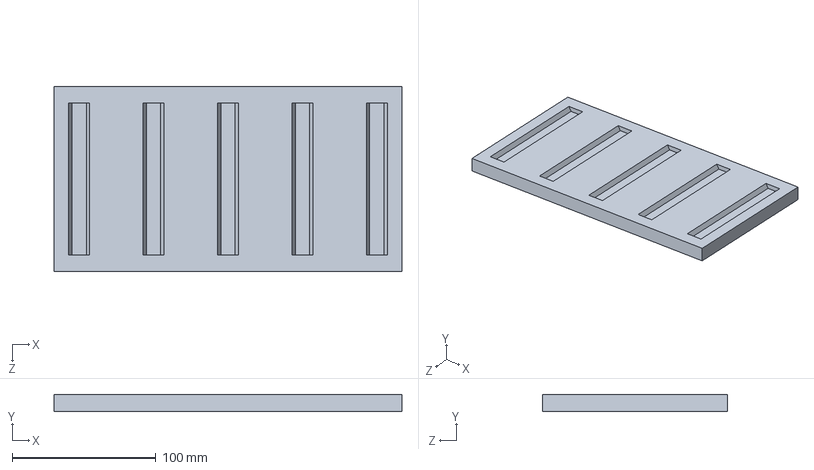
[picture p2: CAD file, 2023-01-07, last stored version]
OpenSource-Platform for publication/jig/Main belt making jig.SLDPRT
242.4 x 12.0 x 129.1 mm

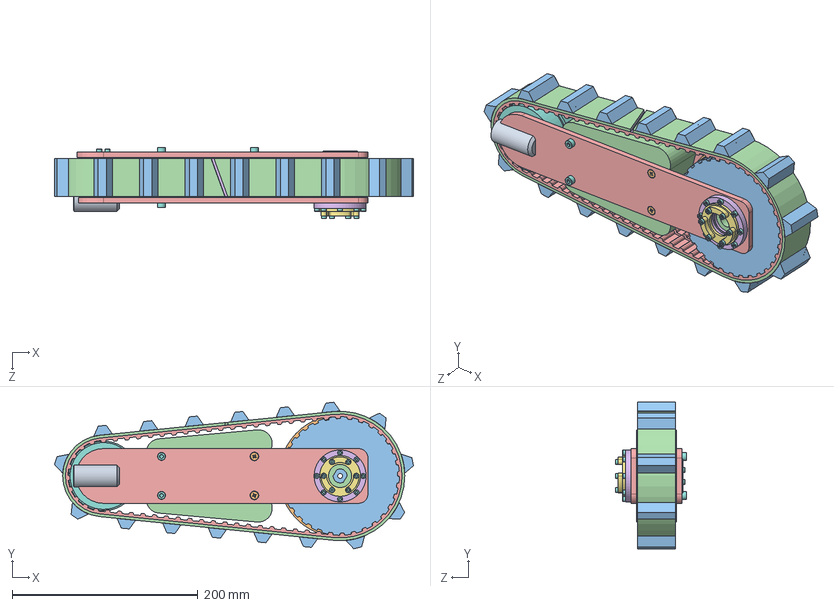
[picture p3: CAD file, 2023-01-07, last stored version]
OpenSource-Platform for publication/Flipper_Unit.SLDASM
386.8 x 157.9 x 77.0 mm
Flipper_Timing pulley_Partition plate
Flipper_Timing pulley x 2
Flipper_Timing pulley_Center attachment x 2
Flipper_Frame x 2
Flipper_Height adjustment plate for connecting claw
Flipper_Connecting claw
Flipper_Idler x 2
Flipper_Idler_Center attachment x 2
Flipper_Tensioner_Positioning plate _Outside x 2
Flipper_Tensioner_Positioning plate _Inside x 2
Flipper_Sliding guide
RDOS8-49-WMC4 x 4
FL6805ZZ x 2
B6800ZZ x 2
hexagon socket head cap screw_jis x 28
cross recessed countersunk head screw_jis x 12
CPL-100(60)
Rubber sheet with CR cloth
330H075
Glue_DBR-100^Flipper_Unit
Glue2_DBR-100^Flipper_Unit

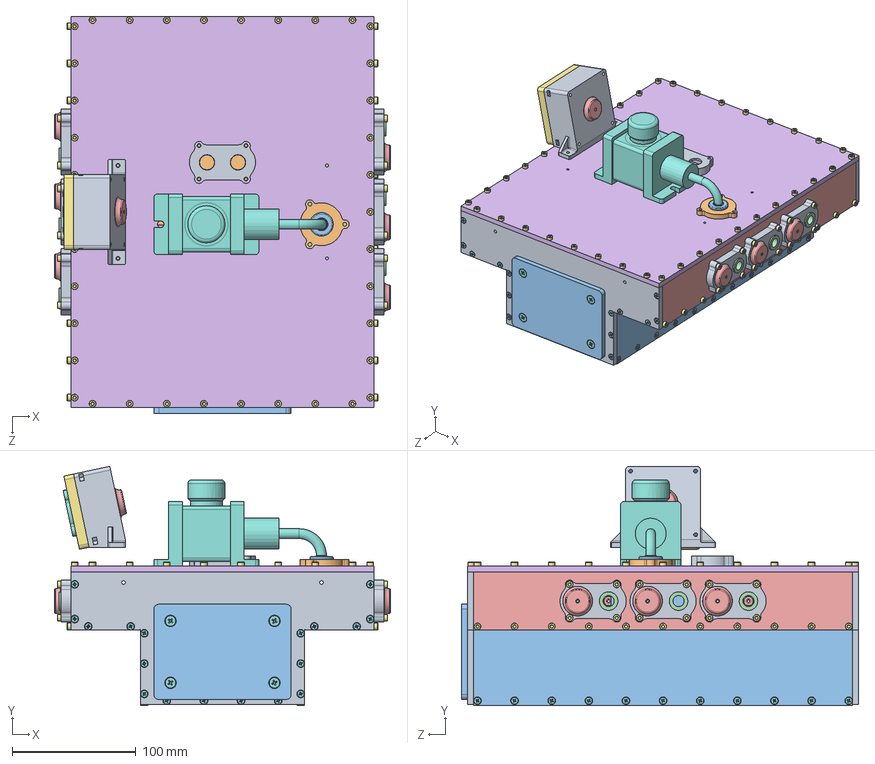
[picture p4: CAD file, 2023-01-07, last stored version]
OpenSource-Platform for publication/Circuit box_Unit.SLDASM
271.5 x 193.4 x 321.0 mm
Circuit box_Plate_Side L R x 2
Circuit box_Bottom plate
Circuit box_Under loft plate x 2
Circuit box_Loft plate x 2
Circuit box_Above loft plate x 2
Circuit box_Top plate
hexagon socket head cap screw_jis x 84
cross recessed countersunk head screw_jis x 84
Driving flipper_Grommet mounting plate x 7
NUC11PAHi7
EPOS x 2
端子台
KYPOM K6 22.2V 3700mA 35C-70C
ｄｃｄｃ
B08ZCV1Q2T
SBOX IDEC NGC-132
NGS25 x 2
Emergency stop switch grommet mount
PG-6 SG-12A
PG-4 NG-79-F x 6
T-145825 x 7
B07YHJK4LN
Middle part^Camera mount
Front part^Camera mount
Rear part
ORG55
Lid

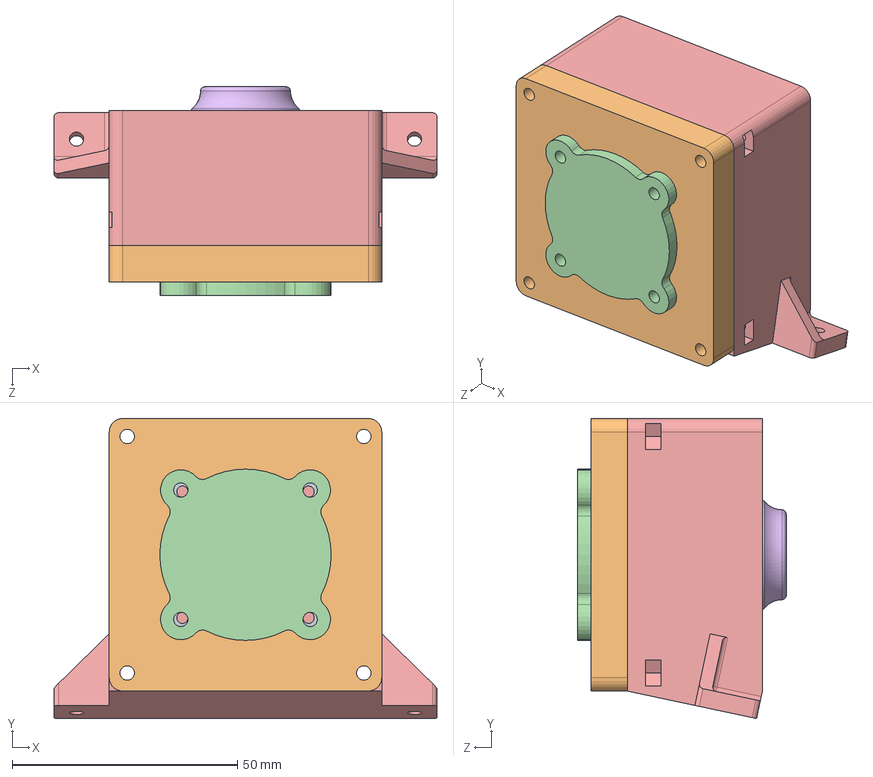
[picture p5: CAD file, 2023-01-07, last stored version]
OpenSource-Platform for publication/Camera mount.SLDASM
85.0 x 66.6 x 46.3 mm
B07YHJK4LN
Middle part^Camera mount
NGS25
Front part^Camera mount
Rear part
T-145825
ORG55

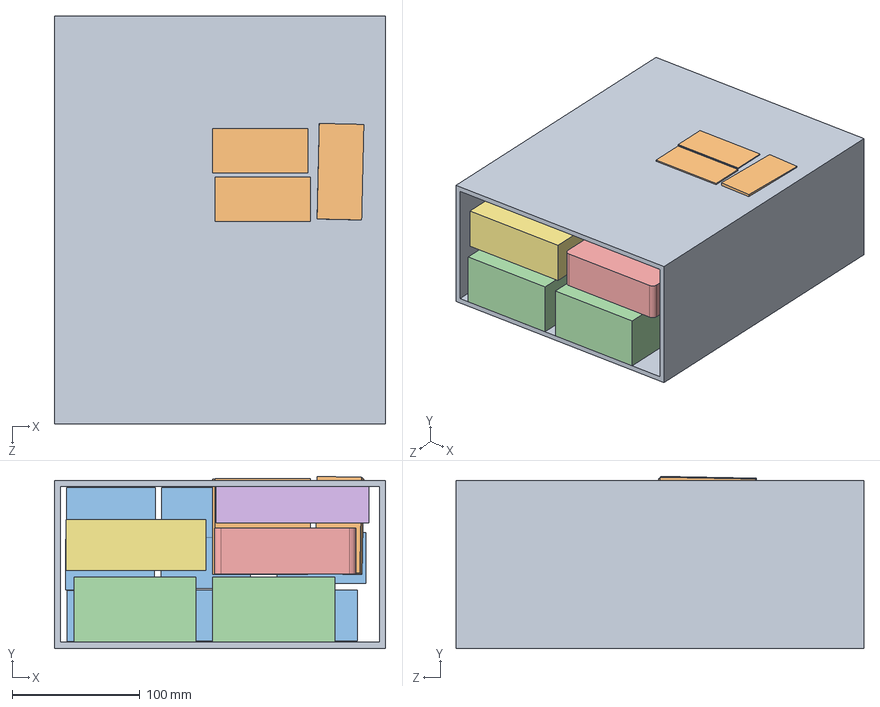
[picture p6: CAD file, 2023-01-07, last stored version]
OpenSource-Platform for publication/Ready-madeParts/内臓/Assem1.SLDASM
260.0 x 135.1 x 320.0 mm
おなか(仮)
48to24 x 3
EPOS x 8
kypom_22.2V_24000mAh x 2
NUC
OPENCR
ビデオサーバー

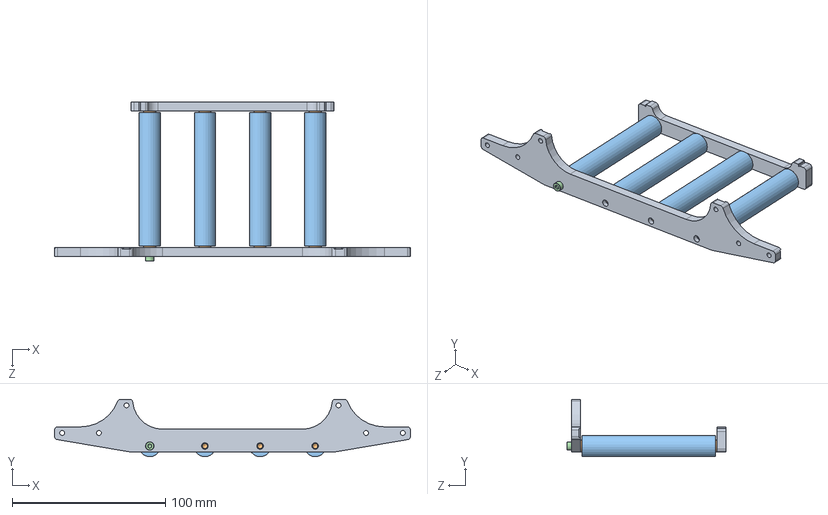
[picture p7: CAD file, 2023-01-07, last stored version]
OpenSource-Platform for publication/Lower roller_Unit.SLDASM
232.4 x 37.5 x 104.0 mm
Lower roller_Connecting rod_Bottom x 2
RDOS8-95-WMC4 x 4
PIJJ14-8-87 x 4
hexagon socket head cap screw_jis

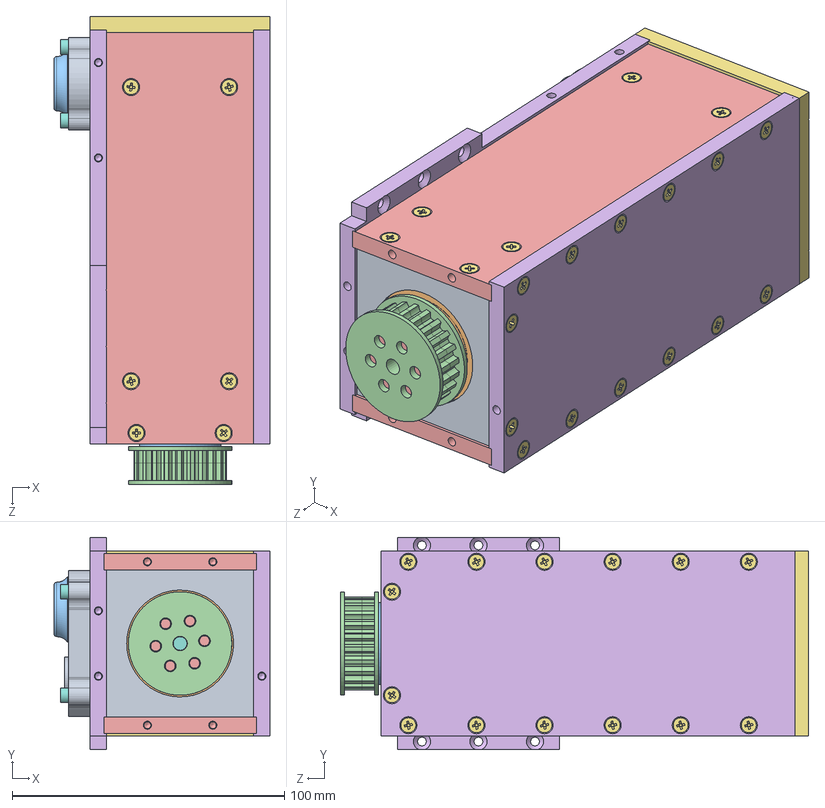
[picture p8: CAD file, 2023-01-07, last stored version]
OpenSource-Platform for publication/Driving flipper_Unit.SLDASM
79.3 x 78.0 x 172.0 mm
Driving flipper_Motor box_Outside cap
Driving flipper_Attachment for motor
Driving flipper_Plate covering O-ring
Driving flipper_Drive pulley x 2
Driving flipper_Motor box_Plate_Side A B x 2
Driving flipper_Motor box_Plate_Side L R x 2
Driving flipper_Motor box_Inside cap
H54-200-S500-R
Driving flipper_Grommet mounting plate
6806DDU(ZZ)
T-145825
NGS25
HPB-4X25-SUS x 6
S36-1A
cross recessed countersunk head screw_jis x 49
hexagon socket head cap screw_jis x 4
PG-4 NG-79-F

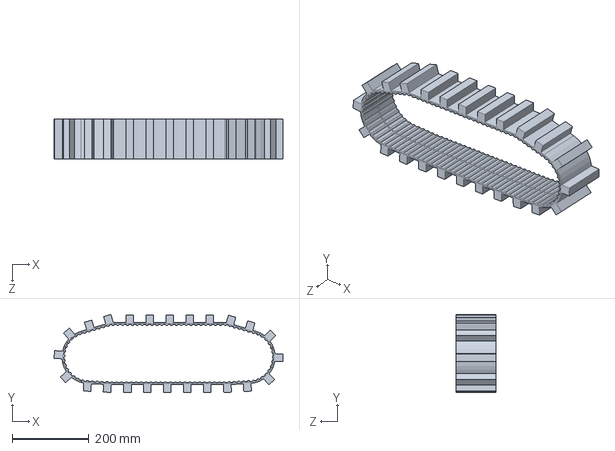
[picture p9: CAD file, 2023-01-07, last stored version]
OpenSource-Platform for publication/Parts/Main crawler belt.SLDPRT
595.3 x 203.0 x 104.6 mm

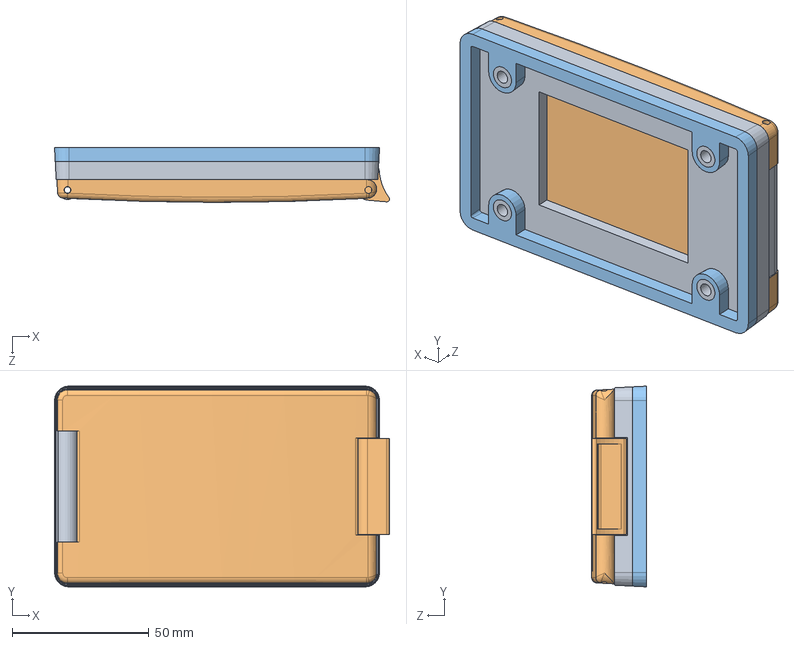
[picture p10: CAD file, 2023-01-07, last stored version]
OpenSource-Platform for publication/Ready-madeParts/SLP9000.SLDASM
122.7 x 73.5 x 20.1 mm
SLP9000A
SLP9000B
SLP9000C

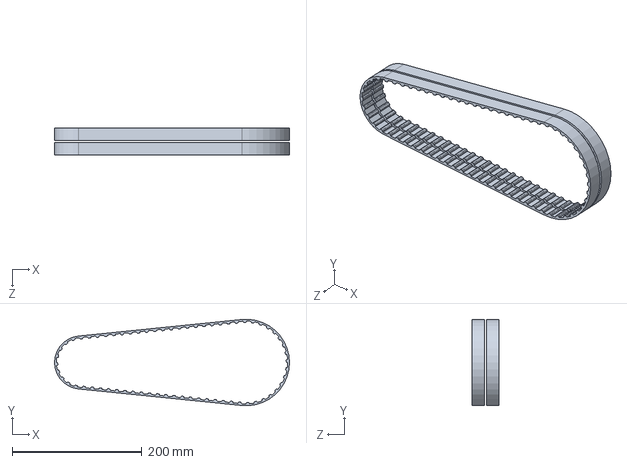
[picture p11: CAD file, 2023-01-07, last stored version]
OpenSource-Platform for publication/jig/フリッパーベルト既製品.sldprt
362.7 x 133.1 x 41.1 mm

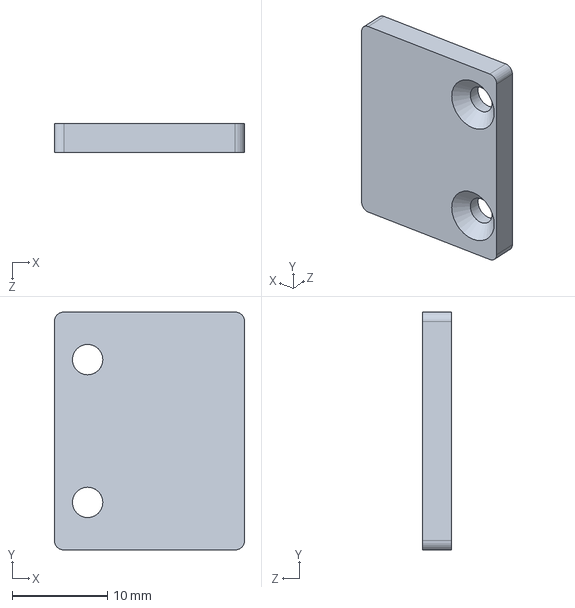
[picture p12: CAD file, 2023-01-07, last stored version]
OpenSource-Platform for publication/Parts/Driving crawler_Tensioner_Positioning plate _Support.SLDPRT
20.0 x 25.0 x 3.00 mm

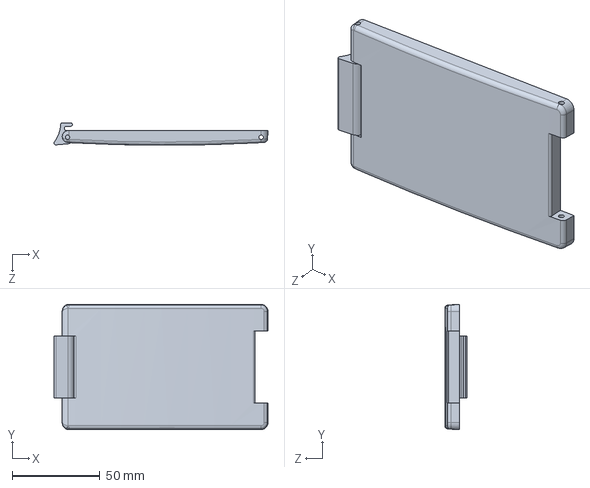
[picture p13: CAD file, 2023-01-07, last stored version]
OpenSource-Platform for publication/Ready-madeParts/SLP9000B.SLDPRT
121.8 x 71.3 x 12.8 mm

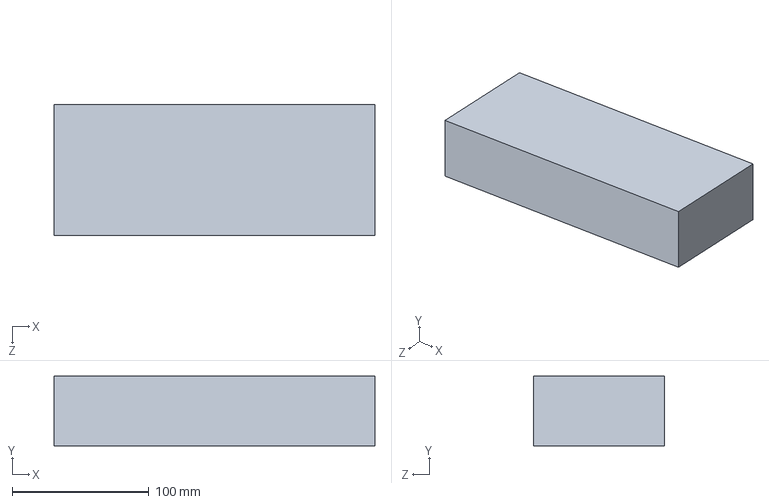
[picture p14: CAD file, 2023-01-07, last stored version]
OpenSource-Platform for publication/Ready-madeParts/内臓/kypom_22.2V_24000mAh.SLDPRT
235.0 x 51.0 x 96.0 mm

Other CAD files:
OpenSource-Platform for publication/front part.sldprt
OpenSource-Platform for publication/Parts/Driving crawler_Tensioner_Positioning plate _Inside.SLDPRT
OpenSource-Platform for publication/Ready-madeParts/PIJJ14-8-87.SLDPRT
OpenSource-Platform for publication/Ready-madeParts/内臓/NUC11PAHi7.SLDPRT
OpenSource-Platform for publication/Driving crawler_Sliding Idler.STL
OpenSource-Platform for publication/Driving flipper_Unit.SLDDRW
OpenSource-Platform for publication/Lid.sldprt
OpenSource-Platform for publication/Parts/Circuit box_Above loft plate.SLDPRT
OpenSource-Platform for publication/Parts/Circuit box_Bottom plate.SLDPRT
OpenSource-Platform for publication/Parts/Circuit box_Loft plate.SLDPRT
OpenSource-Platform for publication/Parts/Circuit box_Plate_Side L R.SLDPRT
OpenSource-Platform for publication/Parts/Circuit box_Top plate.SLDPRT
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
